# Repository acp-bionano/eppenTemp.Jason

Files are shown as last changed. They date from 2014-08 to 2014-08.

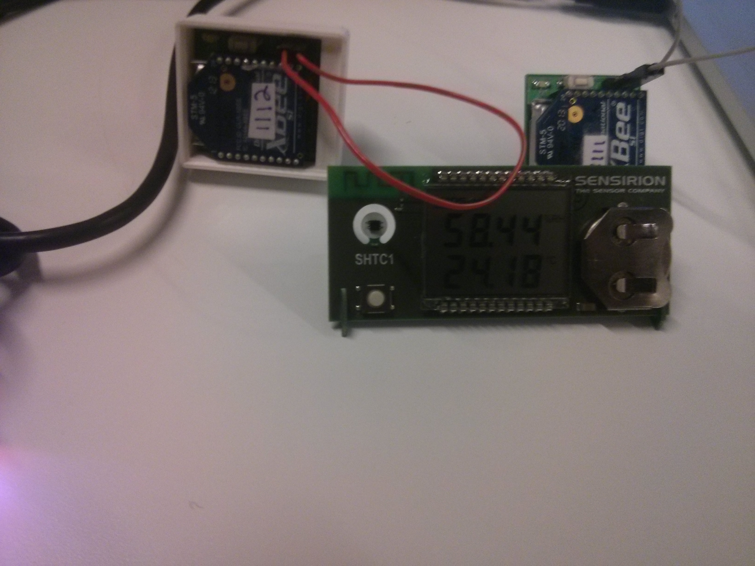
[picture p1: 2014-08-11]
test/tests 08:02/room temp without sleep/ID reference.jpg

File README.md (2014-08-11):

Eppendorf-sized Temperature Sensor
=========
by Andrew Payne and Charles Fracchia

We created a networked temperature sensor that is designed to have the same lower footprint as an eppendorf tube. These sensors are designed to allow the continuous collection of sample temperature in molecular biology experiments.
It is designed to interface with the [Protocol Descriptor Language]() web-system and provide quantifiable information about temperature variability in your protocols.

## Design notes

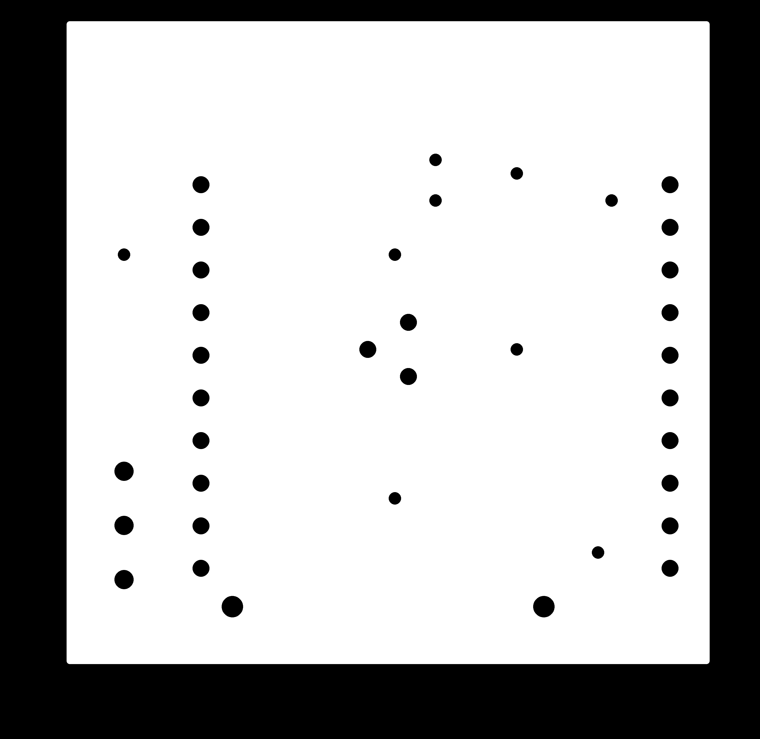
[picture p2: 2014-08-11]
network/draft/outline.png

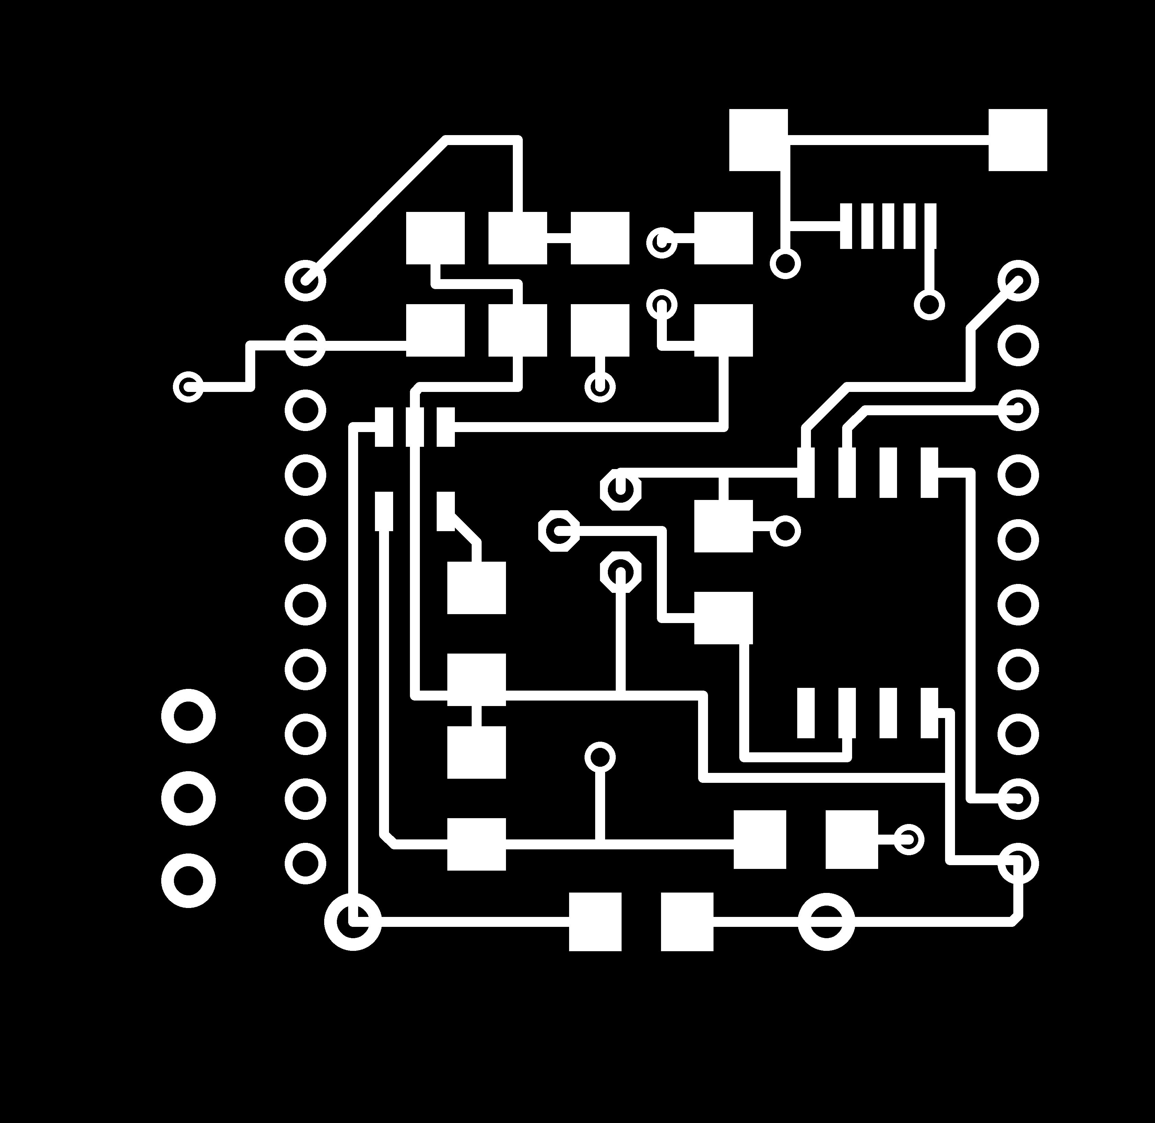
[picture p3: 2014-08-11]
network/draft/traces.png

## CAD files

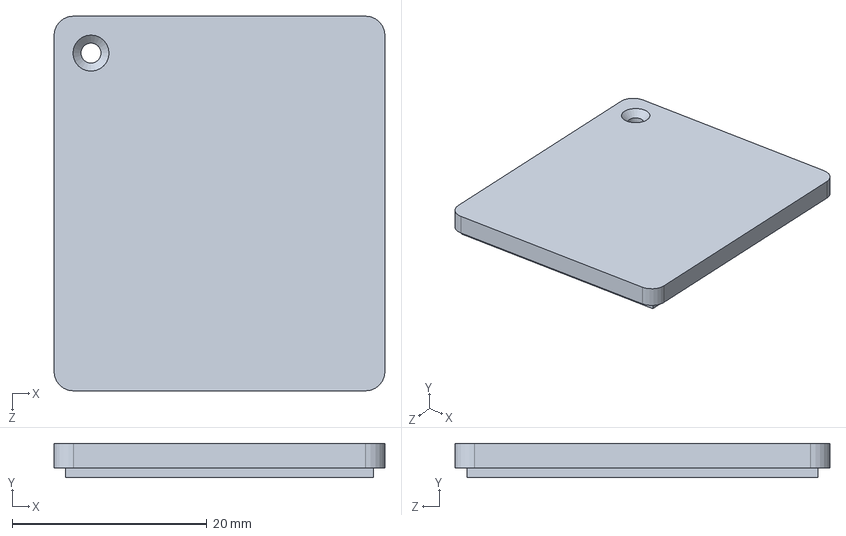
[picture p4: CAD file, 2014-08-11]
case/top casing.SLDPRT
34.0 x 3.50 x 38.5 mm

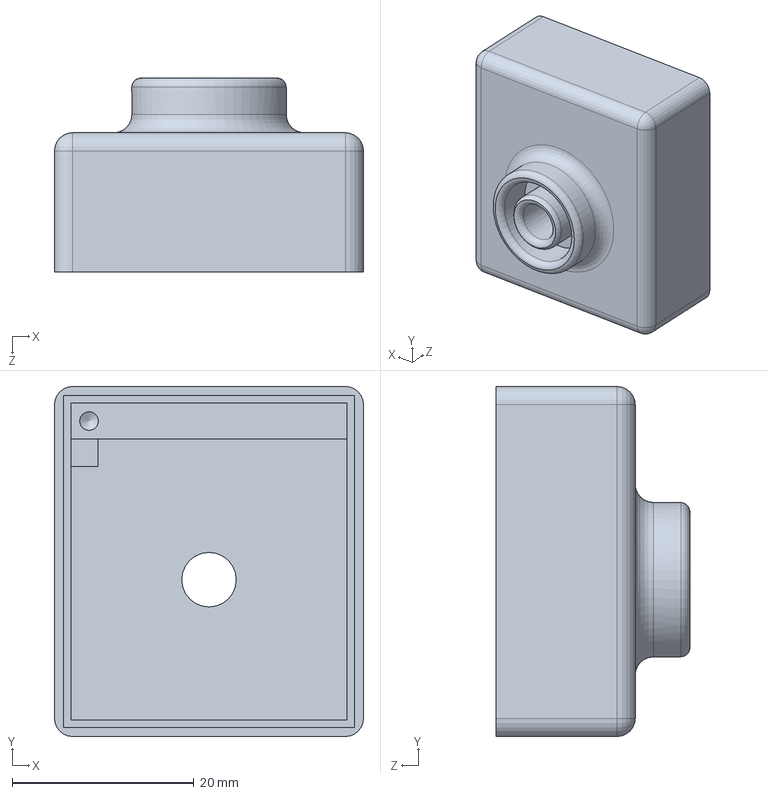
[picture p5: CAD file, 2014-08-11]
case/bottom casing.SLDPRT
34.0 x 38.5 x 21.3 mm

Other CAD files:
case/bottom casing.STL
case/top casing.STL

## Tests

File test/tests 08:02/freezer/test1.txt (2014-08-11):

 1112 25.19 1407113210969
 1112 25.19 1407113212007
 1112 25.19 1407113213047
 1112 25.25 1407113214087
 1112 25.37 1407113215127
 1112 25.37 1407113216166
 1112 25.44 1407113217206
 1112 25.50 1407113218246
 1112 25.62 1407113219285
 1112 25.69 1407113220325
 1112 25.69 1407113221365
 1112 25.62 1407113222404
 1112 25.56 1407113223444
 1112 25.56 1407113224499
 1112 25.50 1407113225539
 1112 25.44 1407113226579
 1112 25.31 1407113227618
 1112 25.25 1407113228658
 1112 25.19 1407113230737
 1112 25.06 1407113231777
 1112 25.44 1407113233856
 1112 25.50 1407113234896
 1112 25.50 1407113235935
 1112 25.50 1407113236975
 1112 25.50 1407113238014
 1112 25.37 1407113239054
 1112 25.00 1407113241149
 1112 24.62 1407113242189
 1112 23.87 1407113243229
 1112 23.19 1407113244252
 1112 22.62 1407113245308
 1112 22.12 1407113246348
 1112 21.56 1407113247387
 1112 21.12 1407113248427
 1112 20.87 1407113249466
 1112 20.62 1407113250506
 1112 20.50 1407113251546
 1112 20.19 1407113252586
 1112 19.87 1407113253625
 1112 19.56 1407113254665
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

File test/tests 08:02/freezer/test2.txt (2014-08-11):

 1112 25.06 1407121928122
 1112 25.44 1407121957791
 1112 25.50 1407121987460
 1112 21.56 1407122017130
 1112 13.19 1407122046816
 1112 10.75 1407122076518
 1112 8.75 1407122106219
 1112 6.81 1407122135921
 1112 5.44 1407122165623
 1112 4.13 1407122195341
 1112 2.75 1407122225058
 1112 1.69 1407122254776
 1112 0.63 1407122284509
 1112 -0.19 1407122314227
 1112 -1.00 1407122343897
 1112 -1.56 1407122373614
 1112 -2.31 1407122403333
 1112 -2.81 1407122433050
 1112 -3.38 1407122462784
 1112 -3.81 1407122492517
 1112 -4.31 1407122522235
 1112 -5.31 1407122551969
 1112 -6.50 1407122581702
 1112 -7.31 1407122611436
 1112 -8.06 1407122641170
 1112 -8.88 1407122670904
 1112 -9.56 1407122700638
 1112 -10.13 1407122730387
 1112 -10.56 1407122760137
 1112 -10.94 1407122789895
 1112 -11.25 1407122819623
 1112 -11.56 1407122849356
 1112 -11.81 1407122879090
 1112 -12.06 1407122908824
 1112 -12.31 1407122938557
 1112 -12.56 1407122968291
 1112 -12.69 1407122998041
 1112 -12.94 1407123027775
 1112 -13.13 1407123057524
 1112 -13.31 1407123087274
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

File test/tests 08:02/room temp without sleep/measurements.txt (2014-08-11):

ID=1112 R=26ID=1112 R=26.87 t= 1407040778535
ID=1112 R=26.87 t= 1407040779590
ID=1112 R=26.94 t= 1407040780630
ID=1112 R=26.94 t= 1407040781669
ID=1111 R=25.19 t= 1407040782405
ID=1112 R=26.94 t= 1407040782709
ID=1111 R=25.25 t= 1407040783445
ID=1112 R=26.94 t= 1407040783749
ID=1111 R=25.25 t= 1407040784484
ID=1112 R=27.00 t= 1407040784804
ID=1111 R=25.25 t= 1407040785540
ID=1112 R=26.94 t= 1407040785844
ID=1111 R=25.25 t= 1407040786580
ID=1112 R=27.00 t= 1407040786884
ID=1111 R=25.31 t= 1407040787620
ID=1112 R=27.00 t= 1407040787923
ID=1111 R=25.31 t= 1407040788659
ID=1112 R=27.00 t= 1407040788963
ID=1111 R=25.31 t= 1407040789699
ID=1112 R=27.00 t= 1407040790018
ID=1111 R=25.31 t= 1407040790738
ID=1112 R=27.00 t= 1407040791058
ID=1111 R=25.31 t= 1407040791778
ID=1112 R=27.00 t= 1407040792098
ID=1111 R=25.31 t= 1407040792817
ID=1112 R=27.00 t= 1407040793137
ID=1111 R=25.31 t= 1407040793857
ID=1112 R=27.06 t= 1407040794177
ID=1111 R=25.37 t= 1407040794897
ID=1112 R=27.06 t= 1407040795233
ID=1111 R=25.37 t= 1407040795937
ID=1112 R=27.06 t= 1407040796272
ID=1111 R=25.37 t= 1407040796976
ID=1112 R=27.06 t= 1407040797312
ID=1111 R=25.37 t= 1407040798015
ID=1112 R=27.06 t= 1407040798351
ID=1111 R=25.44 t= 1407040799055
ID=1112 R=27.06 t= 1407040799391
ID=1111 R=25.44 t= 1407040800095
ID=1112 R=27.06 t= 1407040800431
ID=1111 R=25.50 t= 1407040801134
ID=1112 R=27.12 t= 1407040801486
ID=1111 R=25.50 t= 1407040802174
ID=1112 R=27.12 t= 1407040802526
ID=1111 R=25.50 t= 1407040803214
ID=1112 R=27.12 t= 1407040803566
ID=1111 R=25.56 t= 1407040804254
ID=1112 R=27.12 t= 1407040804605
ID=1111 R=25.56 t= 1407040805293
ID=1112 R=27.12 t= 1407040805645
ID=1111 R=25.56 t= 1407040806333
ID=1112 R=27.12 t= 1407040806701
ID=1111 R=25.56 t= 1407040807372
ID=1112 R=27.12 t= 1407040807740
ID=1111 R=25.56 t= 1407040808412
ID=1112 R=27.12 t= 1407040808780
ID=1111 R=25.56 t= 1407040809468
ID=1112 R=27.19 t= 1407040809819
ID=1111 R=25.56 t= 1407040810507
ID=1112 R=27.12 t= 1407040810859
ID=1111 R=25.56 t= 1407040811547
ID=1112 R=27.12 t= 1407040811915
ID=1111 R=25.56 t= 1407040812586
ID=1112 R=27.19 t= 1407040812954
ID=1111 R=25.56 t= 1407040813626
ID=1112 R=27.19 t= 1407040813995
ID=1111 R=25.56 t= 1407040814666
ID=1112 R=27.19 t= 1407040815033
ID=1111 R=25.62 t= 1407040815705
ID=1112 R=27.19 t= 1407040816073
ID=1111 R=25.62 t= 1407040816745
ID=1112 R=27.19 t= 1407040817129
ID=1111 R=25.62 t= 1407040817784
ID=1112 R=27.19 t= 1407040818168
ID=1111 R=25.62 t= 1407040818824
ID=1112 R=27.19 t= 1407040819208
ID=1111 R=25.62 t= 1407040819864
ID=1112 R=27.19 t= 1407040820248
ID=1111 R=25.62 t= 1407040820904
ID=1112 R=27.19 t= 1407040821287
ID=1111 R=25.62 t= 1407040821943
ID=1112 R=27.25 t= 1407040822327
ID=1111 R=25.62 t= 1407040822983
ID=1112 R=27.19 t= 1407040823383
ID=1111 R=25.62 t= 1407040824022
ID=1112 R=27.25 t= 1407040824422
ID=1111 R=25.69 t= 1407040825062
ID=1112 R=27.25 t= 1407040825462
ID=1111 R=25.69 t= 1407040826101
ID=1112 R=27.25 t= 1407040826501
ID=1111 R=25.69 t= 1407040827157
ID=1112 R=27.25 t= 1407040827557
ID=1111 R=25.75 t= 1407040828197
ID=1112 R=27.25 t= 1407040828597
ID=1111 R=25.69 t= 1407040829236
ID=1112 R=27.25 t= 1407040829636
ID=1111 R=25.75 t= 1407040830276
ID=1112 R=27.25 t= 1407040830676
ID=1111 R=25.75 t= 1407040831316
ID=1112 R=27.25 t= 1407040831715
ID=1111 R=25.75 t= 1407040832355
ID=1112 R=27.31 t= 1407040832755
ID=1111 R=25.75 t= 1407040833395
ID=1112 R=27.25 t= 1407040833811
ID=1111 R=25.75 t= 1407040834435
ID=1112 R=27.31 t= 1407040834851
ID=1111 R=25.81 t= 1407040835474
ID=1112 R=27.31 t= 1407040835890
ID=1111 R=25.81 t= 1407040836514
ID=1112 R=27.31 t= 1407040836930
ID=1111 R=25.81 t= 1407040837553
ID=1112 R=27.31 t= 1407040837969
ID=1111 R=25.87 t= 1407040838593
ID=1112 R=27.31 t= 1407040839025
ID=1111 R=25.81 t= 1407040839633
ID=1112 R=27.31 t= 1407040840065
ID=1111 R=25.87 t= 1407040840672
ID=1112 R=27.31 t= 1407040841104
ID=1111 R=25.87 t= 1407040841712
ID=1112 R=27.37 t= 1407040842144
ID=1111 R=25.87 t= 1407040842751
ID=1112 R=27.31 t= 1407040843183
ID=1111 R=25.94 t= 1407040843791
ID=1112 R=27.37 t= 1407040844225
ID=1111 R=25.87 t= 1407040844847
ID=1112 R=27.37 t= 1407040845279
ID=1111 R=25.94 t= 1407040845886
ID=1112 R=27.37 t= 1407040846318
ID=1111 R=25.94 t= 1407040846926
ID=1112 R=27.37 t= 1407040847358
ID=1111 R=25.94 t= 1407040847966
ID=1112 R=27.37 t= 1407040848398
ID=1111 R=26.00 t= 1407040849005
ID=1112 R=27.37 t= 1407040849437
ID=1111 R=25.94 t= 1407040850045
ID=1112 R=27.44 t= 1407040850477
ID=1111 R=25.94 t= 1407040851085
ID=1112 R=27.44 t= 1407040851517
ID=1111 R=26.00 t= 1407040852125
ID=1112 R=27.37 t= 1407040852572
ID=1111 R=26.00 t= 1407040853164
ID=1112 R=27.37 t= 1407040853612
ID=1111 R=26.00 t= 1407040854204
ID=1112 R=27.44 t= 1407040854652
ID=1111 R=26.06 t= 1407040855243
ID=1112 R=27.37 t= 1407040855691
ID=1111 R=26.06 t= 1407040856283
ID=1112 R=27.44 t= 1407040856731
ID=1111 R=26.00 t= 1407040857322
ID=1112 R=27.44 t= 1407040857786
ID=1111 R=26.00 t= 1407040858362
ID=1112 R=27.44 t= 1407040858826
ID=1111 R=26.00 t= 1407040859402
ID=1112 R=27.44 t= 1407040859865
ID=1111 R=26.00 t= 1407040860441
ID=1112 R=27.44 t= 1407040860905
ID=1111 R=26.00 t= 1407040861497
ID=1112 R=27.50 t= 1407040861945
ID=1111 R=26.00 t= 1407040862537
ID=1112 R=27.44 t= 1407040863000
ID=1111 R=26.00 t= 1407040863576
ID=1112 R=27.50 t= 1407040864040
ID=1111 R=26.00 t= 1407040864616
ID=1112 R=27.50 t= 1407040865080
ID=1111 R=26.00 t= 1407040865656
ID=1112 R=27.50 t= 1407040866119
ID=1111 R=26.00 t= 1407040866695
ID=1112 R=27.50 t= 1407040867159
ID=1111 R=26.00 t= 1407040867734
ID=1112 R=27.50 t= 1407040868214
ID=1111 R=26.00 t= 1407040868774
ID=1112 R=27.50 t= 1407040869254
ID=1111 R=26.06 t= 1407040869814
ID=1112 R=27.50 t= 1407040870294
ID=1111 R=26.06 t= 1407040870854
ID=1112 R=27.50 t= 1407040871333
ID=1111 R=26.06 t= 1407040871893
ID=1112 R=27.56 t= 1407040872373
ID=1111 R=26.06 t= 1407040872933
ID=1112 R=27.50 t= 1407040873429
ID=1111 R=26.06 t= 1407040873972
ID=1112 R=27.50 t= 1407040874468
ID=1111 R=26.12 t= 1407040875012
ID=1112 R=27.56 t= 1407040875508
ID=1111 R=26.12 t= 1407040876052
ID=1112 R=27.50 t= 1407040876548
ID=1111 R=26.12 t= 1407040877092
ID=1112 R=27.56 t= 1407040877587
ID=1111 R=26.12 t= 1407040878131
ID=1112 R=27.56 t= 1407040878643
ID=1111 R=26.19 t= 1407040879170
ID=1112 R=27.56 t= 1407040879682
ID=1111 R=26.19 t= 1407040880210
ID=1112 R=27.56 t= 1407040880722
ID=1111 R=26.19 t= 1407040881266
ID=1112 R=27.56 t= 1407040881762
ID=1111 R=26.19 t= 1407040882305
ID=1112 R=27.56 t= 1407040882801
ID=1111 R=26.19 t= 1407040883345
ID=1112 R=27.56 t= 1407040883857
ID=1111 R=26.25 t= 1407040884385
ID=1112 R=27.56 t= 1407040884897
ID=1111 R=26.19 t= 1407040885425
ID=1112 R=27.62 t= 1407040885936
ID=1111 R=26.25 t= 1407040886464
ID=1112 R=27.62 t= 1407040886976
ID=1111 R=26.25 t= 1407040887504
ID=1112 R=27.56 t= 1407040888015
ID=1111 R=26.19 t= 1407040888543
ID=1112 R=27.62 t= 1407040889071
ID=1111 R=26.25 t= 1407040889583
ID=1112 R=27.62 t= 1407040890111
ID=1111 R=26.31 t= 1407040890623
ID=1112 R=27.62 t= 1407040891150
ID=1111 R=26.25 t= 1407040891662
ID=1112 R=27.62 t= 1407040892190
ID=1111 R=26.31 t= 1407040892702
ID=1112 R=27.62 t= 1407040893229
ID=1111 R=26.31 t= 1407040893741
ID=1112 R=27.62 t= 1407040894285
ID=1111 R=26.31 t= 1407040894781
ID=1112 R=27.69 t= 1407040895325
ID=1111 R=26.31 t= 1407040895821
ID=1112 R=27.69 t= 1407040896364
ID=1111 R=26.31 t= 1407040896860
ID=1112 R=27.69 t= 1407040897404
ID=1111 R=26.31 t= 1407040897900
ID=1112 R=27.69 t= 1407040898444
ID=1111 R=26.25 t= 1407040898939
ID=1112 R=27.69 t= 1407040899483
ID=1111 R=26.31 t= 1407040899979
ID=1112 R=27.69 t= 1407040900539
ID=1111 R=26.25 t= 1407040901019
ID=1112 R=27.69 t= 1407040901578
ID=1111 R=26.31 t= 1407040902058
ID=1112 R=27.69 t= 1407040902618
ID=1111 R=26.31 t= 1407040903114
ID=1112 R=27.69 t= 1407040903658
ID=1111 R=26.31 t= 1407040904153
ID=1112 R=27.69 t= 1407040904697
ID=1111 R=26.31 t= 1407040905193
ID=1112 R=27.69 t= 1407040905737
ID=1111 R=26.31 t= 1407040906233
ID=1112 R=27.69 t= 1407040906793
ID=1111 R=26.31 t= 1407040907272
ID=1112 R=27.69 t= 1407040907832
ID=1111 R=26.31 t= 1407040908312
ID=1112 R=27.69 t= 1407040908872
ID=1111 R=26.31 t= 1407040909352
ID=1112 R=27.75 t= 1407040909911
ID=1111 R=26.37 t= 1407040910391
ID=1112 R=27.75 t= 1407040910951
ID=1111 R=26.31 t= 1407040911431
ID=1112 R=27.75 t= 1407040911991
ID=1111 R=26.31 t= 1407040912470
ID=1112 R=27.75 t= 1407040913046
ID=1111 R=26.37 t= 1407040913510
ID=1112 R=27.75 t= 1407040914086
ID=1111 R=26.37 t= 1407040914550
ID=1112 R=27.75 t= 1407040915126
ID=1111 R=26.37 t= 1407040915589
ID=1112 R=27.75 t= 1407040916165
ID=1111 R=26.37 t= 1407040916629
ID=1112 R=27.75 t= 1407040917205
ID=1111 R=26.37 t= 1407040917669
ID=1112 R=27.75 t= 1407040918260
ID=1111 R=26.37 t= 1407040918708
ID=1112 R=27.75 t= 1407040919300
ID=1111 R=26.37 t= 1407040919764
ID=1112 R=27.81 t= 1407040920340
ID=1111 R=26.37 t= 1407040920803
ID=1112 R=27.75 t= 1407040921379
ID=1111 R=26.37 t= 1407040921843
ID=1112 R=27.81 t= 1407040922435
ID=1111 R=26.44 t= 1407040922883
ID=1112 R=27.81 t= 1407040923475
ID=1111 R=26.44 t= 1407040923922
ID=1112 R=27.81 t= 1407040924514
ID=1111 R=26.44 t= 1407040924962
ID=1112 R=27.81 t= 1407040925554
ID=1111 R=26.44 t= 1407040926001
ID=1112 R=27.81 t= 1407040926593
ID=1111 R=26.50 t= 1407040927041
ID=1112 R=27.81 t= 1407040927649
ID=1111 R=26.50 t= 1407040928081
ID=1112 R=27.81 t= 1407040928688
ID=1111 R=26.50 t= 1407040929120
ID=1112 R=27.81 t= 1407040929728
ID=1111 R=26.50 t= 1407040930160
ID=1112 R=27.81 t= 1407040930768
ID=1111 R=26.56 t= 1407040931200
ID=1112 R=27.81 t= 1407040931807
ID=1111 R=26.56 t= 1407040932239
ID=1112 R=27.81 t= 1407040932847
ID=1111 R=26.56 t= 1407040933279
ID=1112 R=27.81 t= 1407040933902
ID=1111 R=26.56 t= 1407040934318
ID=1112 R=27.87 t= 1407040934942
ID=1111 R=26.56 t= 1407040935374
ID=1112 R=27.87 t= 1407040935982
ID=1111 R=26.56 t= 1407040936414
ID=1112 R=27.87 t= 1407040937022
ID=1111 R=26.56 t= 1407040937454
ID=1112 R=27.87 t= 1407040938061
ID=1111 R=26.56 t= 1407040938493
ID=1112 R=27.87 t= 1407040939117
ID=1111 R=26.56 t= 1407040939533
ID=1112 R=27.87 t= 1407040940156
ID=1111 R=26.56 t= 1407040940572
ID=1112 R=27.87 t= 1407040941196
ID=1111 R=26.56 t= 1407040941612
ID=1112 R=27.87 t= 1407040942236
ID=1111 R=26.56 t= 1407040942651
ID=1112 R=27.87 t= 1407040943275
ID=1111 R=26.56 t= 1407040943691
ID=1112 R=27.87 t= 1407040944331
ID=1111 R=26.56 t= 1407040944731
ID=1112 R=27.87 t= 1407040945371
ID=1111 R=26.56 t= 1407040945771
ID=1112 R=27.94 t= 1407040946410
ID=1111 R=26.56 t= 1407040946810
ID=1112 R=27.94 t= 1407040947450
ID=1111 R=26.62 t= 1407040947850
ID=1112 R=27.94 t= 1407040948489
ID=1111 R=26.62 t= 1407040948889
ID=1112 R=27.94 t= 1407040949529
ID=1111 R=26.62 t= 1407040949929
ID=1112 R=27.94 t= 1407040950585
ID=1111 R=26.62 t= 1407040950984
ID=1112 R=27.94 t= 1407040951624
ID=1111 R=26.62 t= 1407040952024
ID=1112 R=27.94 t= 1407040952664
ID=1111 R=26.62 t= 1407040953064
ID=1112 R=27.94 t= 1407040953704
ID=1111 R=26.62 t= 1407040954103
ID=1112 R=27.94 t= 1407040954743
ID=1111 R=26.62 t= 1407040955143
ID=1112 R=27.94 t= 1407040955799
ID=1111 R=26.62 t= 1407040956182
ID=1112 R=27.94 t= 1407040956838
ID=1111 R=26.62 t= 1407040957222
ID=1112 R=27.94 t= 1407040957878
ID=1111 R=26.69 t= 1407040958262
ID=1112 R=27.94 t= 1407040958918
ID=1111 R=26.69 t= 1407040959301
ID=1112 R=27.94 t= 1407040959957
ID=1111 R=26.69 t= 1407040960341
ID=1112 R=27.94 t= 1407040960997
ID=1111 R=26.69 t= 1407040961381
ID=1112 R=27.94 t= 1407040962036
ID=1111 R=26.75 t= 1407040962420
ID=1112 R=28.00 t= 1407040963092
ID=1111 R=26.75 t= 1407040963460
ID=1112 R=27.94 t= 1407040964131
ID=1111 R=26.69 t= 1407040964499
ID=1112 R=28.00 t= 1407040965171
ID=1111 R=26.75 t= 1407040965539
ID=1112 R=28.00 t= 1407040966211
ID=1111 R=26.75 t= 1407040966579
ID=1112 R=28.00 t= 1407040967251
ID=1111 R=26.75 t= 1407040967618
ID=1112 R=28.00 t= 1407040968290
ID=1111 R=26.75 t= 1407040968658
ID=1112 R=28.00 t= 1407040969346
ID=1111 R=26.75 t= 1407040969698
ID=1112 R=28.00 t= 1407040970386
ID=1111 R=26.75 t= 1407040970738
ID=1112 R=28.00 t= 1407040971425
ID=1111 R=26.69 t= 1407040971777
ID=1112 R=28.06 t= 1407040972465
ID=1111 R=26.75 t= 1407040972833
ID=1112 R=28.00 t= 1407040973505
ID=1111 R=26.75 t= 1407040973873
ID=1112 R=28.00 t= 1407040974544
ID=1111 R=26.75 t= 1407040974912
ID=1112 R=28.06 t= 1407040975584
ID=1111 R=26.75 t= 1407040975952
ID=1112 R=28.06 t= 1407040976639
ID=1111 R=26.75 t= 1407040976991
ID=1112 R=28.06 t= 1407040977679
ID=1111 R=26.75 t= 1407040978031
ID=1112 R=28.06 t= 1407040978719
ID=1111 R=26.75 t= 1407040979070
ID=1112 R=28.06 t= 1407040979758
ID=1111 R=26.75 t= 1407040980110
ID=1112 R=28.06 t= 1407040980798
ID=1111 R=26.69 t= 1407040981150
ID=1112 R=28.06 t= 1407040981838
ID=1111 R=26.75 t= 1407040982189
ID=1112 R=28.06 t= 1407040982893
ID=1111 R=26.75 t= 1407040983229
ID=1112 R=28.06 t= 1407040983933
ID=1111 R=26.81 t= 1407040984269
ID=1112 R=28.06 t= 1407040984972
ID=1111 R=26.81 t= 1407040985308
ID=1112 R=28.06 t= 1407040986012
ID=1111 R=26.81 t= 1407040986348
ID=1112 R=28.06 t= 1407040987051
ID=1111 R=26.81 t= 1407040987388
ID=1112 R=28.06 t= 1407040988091
ID=1111 R=26.81 t= 1407040988427
ID=1112 R=28.06 t= 1407040989131
ID=1111 R=26.87 t= 1407040989467
ID=1112 R=28.06 t= 1407040990187
ID=1111 R=26.87 t= 1407040990506
ID=1112 R=28.12 t= 1407040991226
ID=1111 R=26.87 t= 1407040991546
ID=1112 R=28.12 t= 1407040992266
ID=1111 R=26.87 t= 1407040992586
ID=1112 R=28.06 t= 1407040993306
ID=1111 R=26.87 t= 1407040993625
ID=1112 R=28.12 t= 1407040994345
ID=1111 R=26.94 t= 1407040994665
ID=1112 R=28.12 t= 1407040995401
ID=1111 R=26.94 t= 1407040995704
ID=1112 R=28.06 t= 1407040996440
ID=1111 R=26.94 t= 1407040996760
ID=1112 R=28.12 t= 1407040997480
ID=1111 R=27.00 t= 1407040997800
ID=1112 R=28.12 t= 1407040998520
ID=1111 R=26.94 t= 1407040998839
ID=1112 R=28.12 t= 1407040999559
ID=1111 R=26.94 t= 1407040999879
ID=1112 R=28.12 t= 1407041000615
ID=1111 R=26.94 t= 1407041000919
ID=1112 R=28.12 t= 1407041001655
ID=1111 R=26.94 t= 1407041001958
ID=1112 R=28.12 t= 1407041002694
ID=1111 R=26.94 t= 1407041002998
ID=1112 R=28.12 t= 1407041003734
ID=1111 R=26.94 t= 1407041004038
ID=1112 R=28.19 t= 1407041004773
ID=1111 R=26.94 t= 1407041005077
ID=1112 R=28.12 t= 1407041005813
ID=1111 R=26.87 t= 1407041006117
ID=1112 R=28.12 t= 1407041006853
ID=1111 R=26.94 t= 1407041007157
ID=1112 R=28.12 t= 1407041007908
ID=1111 R=26.94 t= 1407041008196
ID=1112 R=28.12 t= 1407041008948
ID=1111 R=26.94 t= 1407041009236
ID=1112 R=28.12 t= 1407041009987
ID=1111 R=26.94 t= 1407041010276
ID=1112 R=28.19 t= 1407041011027
ID=1111 R=26.94 t= 1407041011315
ID=1112 R=28.19 t= 1407041012067
ID=1111 R=26.94 t= 1407041012355
ID=1112 R=28.19 t= 1407041013106
ID=1111 R=26.94 t= 1407041013394
ID=1112 R=28.19 t= 1407041014162
ID=1111 R=26.94 t= 1407041014434
ID=1112 R=28.19 t= 1407041015202
ID=1111 R=26.94 t= 1407041015474
ID=1112 R=28.19 t= 1407041016241
ID=1111 R=26.94 t= 1407041016513
ID=1112 R=28.19 t= 1407041017281
ID=1111 R=26.94 t= 1407041017553
ID=1112 R=28.19 t= 1407041018321
ID=1111 R=26.94 t= 1407041018609
ID=1112 R=28.19 t= 1407041019360
ID=1111 R=26.94 t= 1407041019648
ID=1112 R=28.19 t= 1407041020400
ID=1111 R=27.00 t= 1407041020688
ID=1112 R=28.19 t= 1407041021455
ID=1111 R=27.00 t= 1407041021727
ID=1112 R=28.19 t= 1407041022495
ID=1111 R=27.00 t= 1407041022767
ID=1112 R=28.19 t= 1407041023534
ID=1111 R=27.06 t= 1407041023807
ID=1112 R=28.19 t= 1407041024574
ID=1111 R=27.06 t= 1407041024846
ID=1112 R=28.25 t= 1407041025614
ID=1111 R=27.06 t= 1407041025886
ID=1112 R=28.19 t= 1407041026670
ID=1111 R=27.06 t= 1407041026925
ID=1112 R=28.25 t= 1407041027709
ID=1111 R=27.06 t= 1407041027965
ID=1112 R=28.25 t= 1407041028749
ID=1111 R=27.06 t= 1407041029005
ID=1112 R=28.25 t= 1407041029788
ID=1111 R=27.12 t= 1407041030044
ID=1112 R=28.25 t= 1407041030828
ID=1111 R=27.12 t= 1407041031084
ID=1112 R=28.25 t= 1407041031867
ID=1111 R=27.12 t= 1407041032123
ID=1112 R=28.25 t= 1407041032923
ID=1111 R=27.12 t= 1407041033163
ID=1112 R=28.25 t= 1407041033963
ID=1111 R=27.12 t= 1407041034203
ID=1112 R=28.25 t= 1407041035002
ID=1111 R=27.19 t= 1407041035242
ID=1112 R=28.25 t= 1407041036042
ID=1111 R=27.19 t= 1407041036282
ID=1112 R=28.25 t= 1407041037082
ID=1111 R=27.19 t= 1407041037338
ID=1112 R=28.25 t= 1407041038121
ID=1111 R=27.19 t= 1407041038377
ID=1112 R=28.25 t= 1407041039161
ID=1111 R=27.19 t= 1407041039417
ID=1112 R=28.25 t= 1407041040217
ID=1111 R=27.19 t= 1407041040456
ID=1112 R=28.25 t= 1407041041256
ID=1111 R=27.25 t= 1407041041496
ID=1112 R=28.25 t= 1407041042296
ID=1111 R=27.19 t= 1407041042536
ID=1112 R=28.31 t= 1407041043335
ID=1111 R=27.19 t= 1407041043575
ID=1112 R=28.31 t= 1407041044375
ID=1111 R=27.25 t= 1407041044615
ID=1112 R=28.31 t= 1407041045431
ID=1111 R=27.25 t= 1407041045655
ID=1112 R=28.31 t= 1407041046470
ID=1111 R=27.25 t= 1407041046694
ID=1112 R=28.25 t= 1407041047510
ID=1111 R=27.25 t= 1407041047734
ID=1112 R=28.25 t= 1407041048549
ID=1111 R=27.25 t= 1407041048773
ID=1112 R=28.25 t= 1407041049589
ID=1111 R=27.25 t= 1407041049813
ID=1112 R=28.31 t= 1407041050645
ID=1111 R=27.25 t= 1407041050853
ID=1112 R=28.31 t= 1407041051684
ID=1111 R=27.25 t= 1407041051892
ID=1112 R=28.31 t= 1407041052724
ID=1111 R=27.25 t= 1407041052932
ID=1112 R=28.31 t= 1407041053764
ID=1111 R=27.25 t= 1407041053971
ID=1112 R=28.31 t= 1407041054803
ID=1111 R=27.25 t= 1407041055011
ID=1112 R=28.31 t= 1407041055859
ID=1111 R=27.25 t= 1407041056051
ID=1112 R=28.31 t= 1407041056898
ID=1111 R=27.31 t= 1407041057090
ID=1112 R=28.31 t= 1407041057938
ID=1111 R=27.25 t= 1407041058130
ID=1112 R=28.31 t= 1407041058978
ID=1111 R=27.31 t= 1407041059170
ID=1112 R=28.31 t= 1407041060017
ID=1111 R=27.31 t= 1407041060209
ID=1112 R=28.31 t= 1407041061057
ID=1111 R=27.31 t= 1407041061249
ID=1112 R=28.31 t= 1407041062097
ID=1111 R=27.31 t= 1407041062288
ID=1112 R=28.31 t= 1407041063152
ID=1111 R=27.31 t= 1407041063344
ID=1112 R=28.31 t= 1407041064192
ID=1111 R=27.37 t= 1407041064384
ID=1112 R=28.31 t= 1407041065232
ID=1111 R=27.37 t= 1407041065423
ID=1112 R=28.31 t= 1407041066271
ID=1111 R=27.37 t= 1407041066463
ID=1112 R=28.31 t= 1407041067310
ID=1111 R=27.31 t= 1407041067502
ID=1112 R=28.31 t= 1407041068350
ID=1111 R=27.31 t= 1407041068542
ID=1112 R=28.37 t= 1407041069406
ID=1111 R=27.31 t= 1407041069582
ID=1112 R=28.37 t= 1407041070445
ID=1111 R=27.31 t= 1407041070622
ID=1112 R=28.37 t= 1407041071485
ID=1111 R=27.31 t= 1407041071661
ID=1112 R=28.37 t= 1407041072525
ID=1111 R=27.37 t= 1407041072701
ID=1112 R=28.37 t= 1407041073564
ID=1111 R=27.31 t= 1407041073741
ID=1112 R=28.37 t= 1407041074604
ID=1111 R=27.31 t= 1407041074780
ID=1112 R=28.37 t= 1407041075660
ID=1111 R=27.31 t= 1407041075820
ID=1112 R=28.37 t= 1407041076699
ID=1111 R=27.31 t= 1407041076859
ID=1112 R=28.37 t= 1407041077739
ID=1111 R=27.31 t= 1407041077899
ID=1112 R=28.37 t= 1407041078779
ID=1111 R=27.31 t= 1407041078939
ID=1112 R=28.37 t= 1407041079818
ID=1111 R=27.31 t= 1407041079978
ID=1112 R=28.37 t= 1407041080874
ID=1111 R=27.25 t= 1407041081018
ID=1112 R=28.37 t= 1407041081913
ID=1111 R=27.25 t= 1407041082057
ID=1112 R=28.44 t= 1407041082953
ID=1111 R=27.25 t= 1407041083097
ID=1112 R=28.37 t= 1407041083993
ID=1111 R=27.25 t= 1407041084137
ID=1112 R=28.37 t= 1407041085033
ID=1111 R=27.31 t= 1407041085176
ID=1112 R=28.44 t= 1407041086088
ID=1111 R=27.31 t= 1407041086216
ID=1112 R=28.44 t= 1407041087127
ID=1111 R=27.31 t= 1407041087256
ID=1112 R=28.44 t= 1407041088167
ID=1111 R=27.31 t= 1407041088295
ID=1112 R=28.44 t= 1407041089207
ID=1111 R=27.31 t= 1407041089335
ID=1112 R=28.44 t= 1407041090247
ID=1111 R=27.31 t= 1407041090374
ID=1112 R=28.44 t= 1407041091286
ID=1111 R=27.31 t= 1407041091414
ID=1112 R=28.44 t= 1407041092342
ID=1111 R=27.31 t= 1407041092454
ID=1112 R=28.44 t= 1407041093382
ID=1111 R=27.31 t= 1407041093509
ID=1112 R=28.44 t= 1407041094421
ID=1111 R=27.31 t= 1407041094549
ID=1112 R=28.44 t= 1407041095461
ID=1111 R=27.37 t= 1407041095588
ID=1112 R=28.44 t= 1407041096500
ID=1111 R=27.31 t= 1407041096628
ID=1112 R=28.44 t= 1407041097540
ID=1111 R=27.31 t= 1407041097668
ID=1112 R=28.44 t= 1407041098596
ID=1111 R=27.37 t= 1407041098708
ID=1112 R=28.44 t= 1407041099635
ID=1111 R=27.31 t= 1407041099747
ID=1112 R=28.44 t= 1407041100675
ID=1111 R=27.31 t= 1407041100787
ID=1112 R=28.44 t= 1407041101715
ID=1111 R=27.31 t= 1407041101827
ID=1112 R=28.44 t= 1407041102754
ID=1111 R=27.31 t= 1407041102866
ID=1112 R=28.44 t= 1407041103794
ID=1111 R=27.37 t= 1407041103906
ID=1112 R=28.50 t= 1407041104849
ID=1111 R=27.31 t= 1407041104945
ID=1112 R=28.44 t= 1407041105889
ID=1111 R=27.31 t= 1407041105985
ID=1112 R=28.44 t= 1407041106929
ID=1111 R=27.31 t= 1407041107024
ID=1112 R=28.50 t= 1407041107968
ID=1111 R=27.31 t= 1407041108064
ID=1112 R=28.44 t= 1407041109008
ID=1111 R=27.31 t= 1407041109120
ID=1112 R=28.50 t= 1407041110047
ID=1111 R=27.31 t= 1407041110159
ID=1112 R=28.50 t= 1407041111103
ID=1111 R=27.31 t= 1407041111199
ID=1112 R=28.50 t= 1407041112142
ID=1111 R=27.37 t= 1407041112239
ID=1112 R=28.50 t= 1407041113182
ID=1111 R=27.37 t= 1407041113278
ID=1112 R=28.50 t= 1407041114222
ID=1111 R=27.37 t= 1407041114318
ID=1112 R=28.50 t= 1407041115261
ID=1111 R=27.37 t= 1407041115357
ID=1112 R=28.50 t= 1407041116301
ID=1111 R=27.44 t= 1407041116397
ID=1112 R=28.50 t= 1407041117358
ID=1111 R=27.44 t= 1407041117437
ID=1112 R=28.50 t= 1407041118396
ID=1111 R=27.44 t= 1407041118476
ID=1112 R=28.50 t= 1407041119436
ID=1111 R=27.44 t= 1407041119516
ID=1112 R=28.50 t= 1407041120475
ID=1111 R=27.44 t= 1407041120555
ID=1112 R=28.50 t= 1407041121515
ID=1111 R=27.37 t= 1407041121595
ID=1112 R=28.50 t= 1407041122555
ID=1111 R=27.37 t= 1407041122635
ID=1112 R=28.50 t= 1407041123611
ID=1111 R=27.37 t= 1407041123674
ID=1112 R=28.50 t= 1407041124650
ID=1111 R=27.37 t= 1407041124714
ID=1112 R=28.50 t= 1407041125690
ID=1111 R=27.37 t= 1407041125754
ID=1112 R=28.50 t= 1407041126730
ID=1111 R=27.37 t= 1407041126793
ID=1112 R=28.50 t= 1407041127769
ID=1111 R=27.37 t= 1407041127833
ID=1112 R=28.56 t= 1407041128809
ID=1111 R=27.37 t= 1407041128889
ID=1112 R=28.50 t= 1407041129848
ID=1111 R=27.37 t= 1407041129928
ID=1112 R=28.56 t= 1407041130904
ID=1111 R=27.37 t= 1407041130968
ID=1112 R=28.50 t= 1407041131943
ID=1111 R=27.37 t= 1407041132008
ID=1112 R=28.50 t= 1407041132983
ID=1111 R=27.37 t= 1407041133047
ID=1112 R=28.56 t= 1407041134023
ID=1111 R=27.37 t= 1407041134087
ID=1112 R=28.50 t= 1407041135062
ID=1111 R=27.37 t= 1407041135127
ID=1112 R=28.56 t= 1407041136102
ID=1111 R=27.37 t= 1407041136166
ID=1112 R=28.50 t= 1407041137157
ID=1111 R=27.37 t= 1407041137206
ID=1112 R=28.56 t= 1407041138197
ID=1111 R=27.44 t= 1407041138245
ID=1112 R=28.50 t= 1407041139237
ID=1111 R=27.37 t= 1407041139285
ID=1112 R=28.56 t= 1407041140276
ID=1111 R=27.44 t= 1407041140325
ID=1112 R=28.56 t= 1407041141316
ID=1111 R=27.44 t= 1407041141364
ID=1112 R=28.50 t= 1407041142356
ID=1111 R=27.44 t= 1407041142404
ID=1112 R=28.56 t= 1407041143411
ID=1111 R=27.44 t= 1407041143443
ID=1112 R=28.56 t= 1407041144451
ID=1111 R=27.44 t= 1407041144483
ID=1112 R=28.56 t= 1407041145491
ID=1111 R=27.44 t= 1407041145522
ID=1112 R=28.56 t= 1407041146530
ID=1111 R=27.44 t= 1407041146562
ID=1112 R=28.56 t= 1407041147570
ID=1111 R=27.50 t= 1407041147602
ID=1112 R=28.56 t= 1407041148609
ID=1111 R=27.50 t= 1407041148642
ID=1112 R=28.56 t= 1407041149649
ID=1111 R=27.50 t= 1407041149681
ID=1112 R=28.56 t= 1407041150705
ID=1111 R=27.50 t= 1407041150721
ID=1112 R=28.56 t= 1407041151744
ID=1111 R=27.50 t= 1407041151760
ID=1112 R=28.56 t= 1407041152784
ID=1111 R=27.50 t= 1407041152800
ID=1112 R=28.56 t= 1407041153824
ID=1111 R=27.50 t= 1407041153856
ID=1112 R=28.56 t= 1407041154863
ID=1111 R=27.50 t= 1407041154895
ID=1112 R=28.56 t= 1407041155919
ID=1111 R=27.56 t= 1407041155935
ID=1112 R=28.56 t= 1407041156958
ID=1111 R=27.56 t= 1407041156974
ID=1112 R=28.56 t= 1407041157998
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

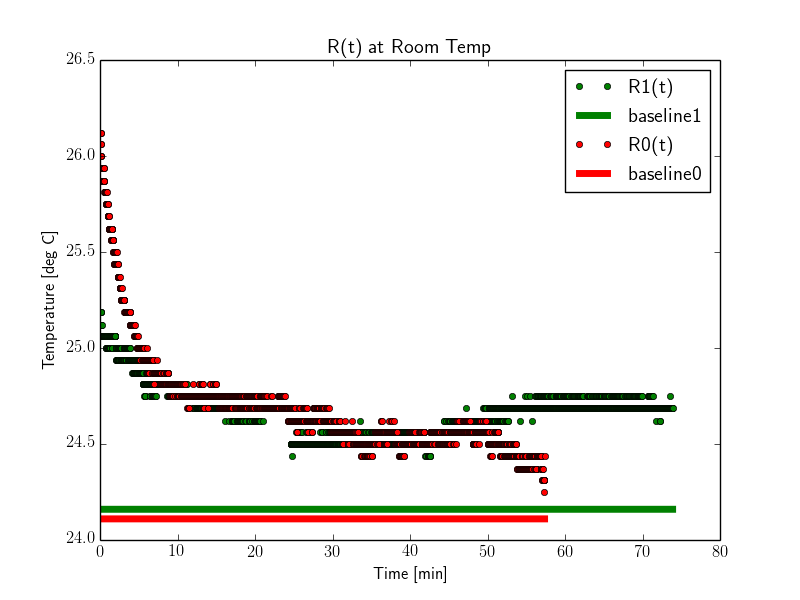
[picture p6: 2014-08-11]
test/tests 08:02/room temp with sleep/combined.png

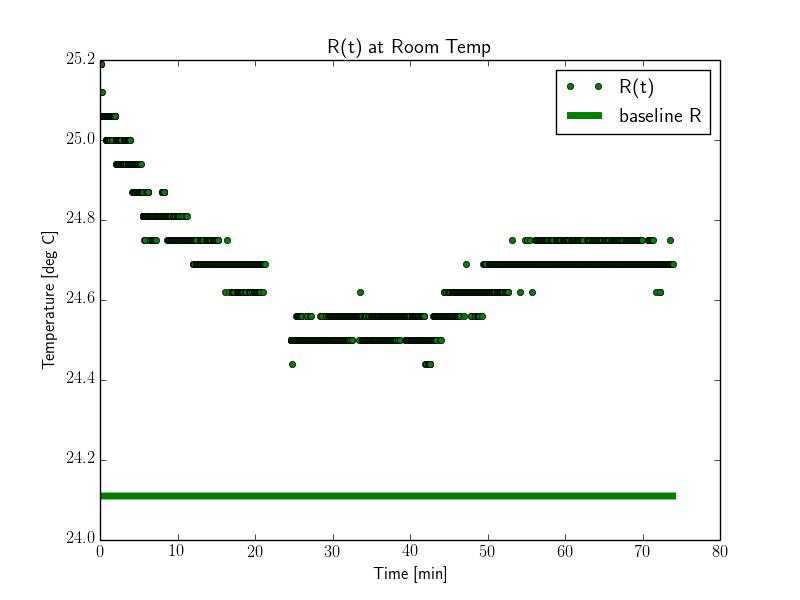
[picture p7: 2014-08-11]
test/tests 08:02/room temp with sleep/rt2.png

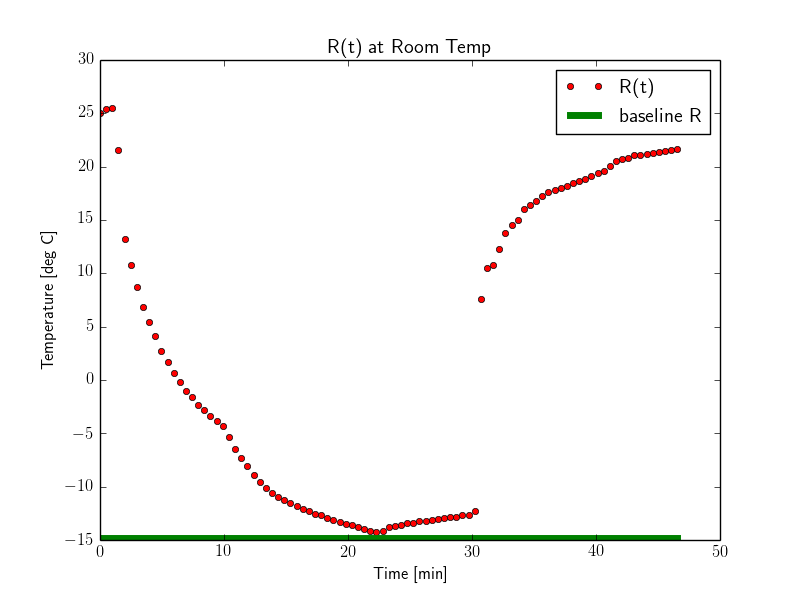
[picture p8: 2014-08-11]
test/tests 08:02/freezer/test2.png

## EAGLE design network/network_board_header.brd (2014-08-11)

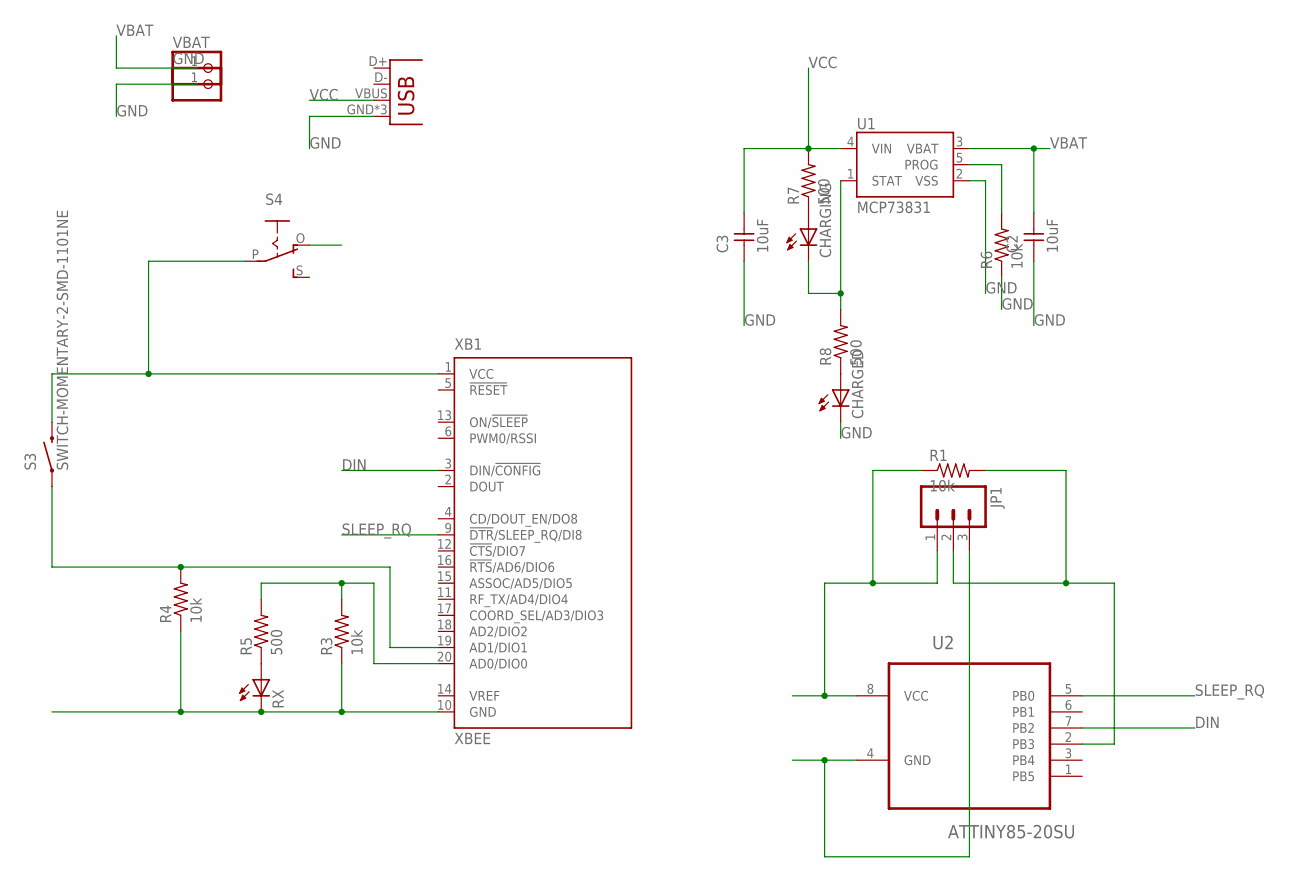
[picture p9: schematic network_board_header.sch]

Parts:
C2, C3: 10uF; 1206
CHARGED: LED1206; 1206
CHARGING: LED1206; 1206
GND: PINHD-1X1CB; 1X01-CLEANBIG
JP1: M03PTH; 1X03
R1: 10k; 1206
R3, R4, R6: 10k; R1206
R5, R7, R8: 500; R1206
RX: LED1206; 1206
S3: SWITCH-MOMENTARY-2-SMD-1101NE; TACTILE-SWITCH-1101NE
S4: EG1218S; EG1218
U1: MCP73831; SOT23-5
U2: ATTINY85-20SU; SOIC127P798X216-8N
VBAT: PINHD-1X1CB; 1X01-CLEANBIG
X1: USB-MICROB
XB1: XBEE

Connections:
DIN: U2.7 (PB2), XB1.3 (DIN/!CONFIG)
GND: C2.1, C3.1, CHARGED.2 (C), GND.1, JP1.3, R3.1, R4.1, R6.1, RX.2 (C), U1.2 (VSS), U2.4 (GND), X1.GND, X1.MT1 (GND), X1.MT2 (GND), XB1.10 (GND)
unnamed: R4.2, S3.P$1 (1), XB1.19 (AD1/DIO1)
unnamed: R5.1, RX.1 (A)
unnamed: R3.2, R5.2, XB1.20 (AD0/DIO0)
unnamed: R6.2, U1.5 (PROG)
unnamed: CHARGING.1 (A), R7.1
unnamed: CHARGED.1 (A), R8.1
unnamed: CHARGING.2 (C), R8.2, U1.1 (STAT)
unnamed: JP1.2, R1.2, U2.2 (PB3)
SLEEP_RQ: U2.5 (PB0), XB1.9 (!DTR!/SLEEP_RQ/DI8)
VBAT: C2.2, S4.O, U1.3 (VBAT), VBAT.1
VCC: C3.2, R7.2, U1.4 (VIN), X1.VBUS
VIN: JP1.1, R1.1, S3.P$2 (2), S4.P, U2.8 (VCC), XB1.1 (VCC)

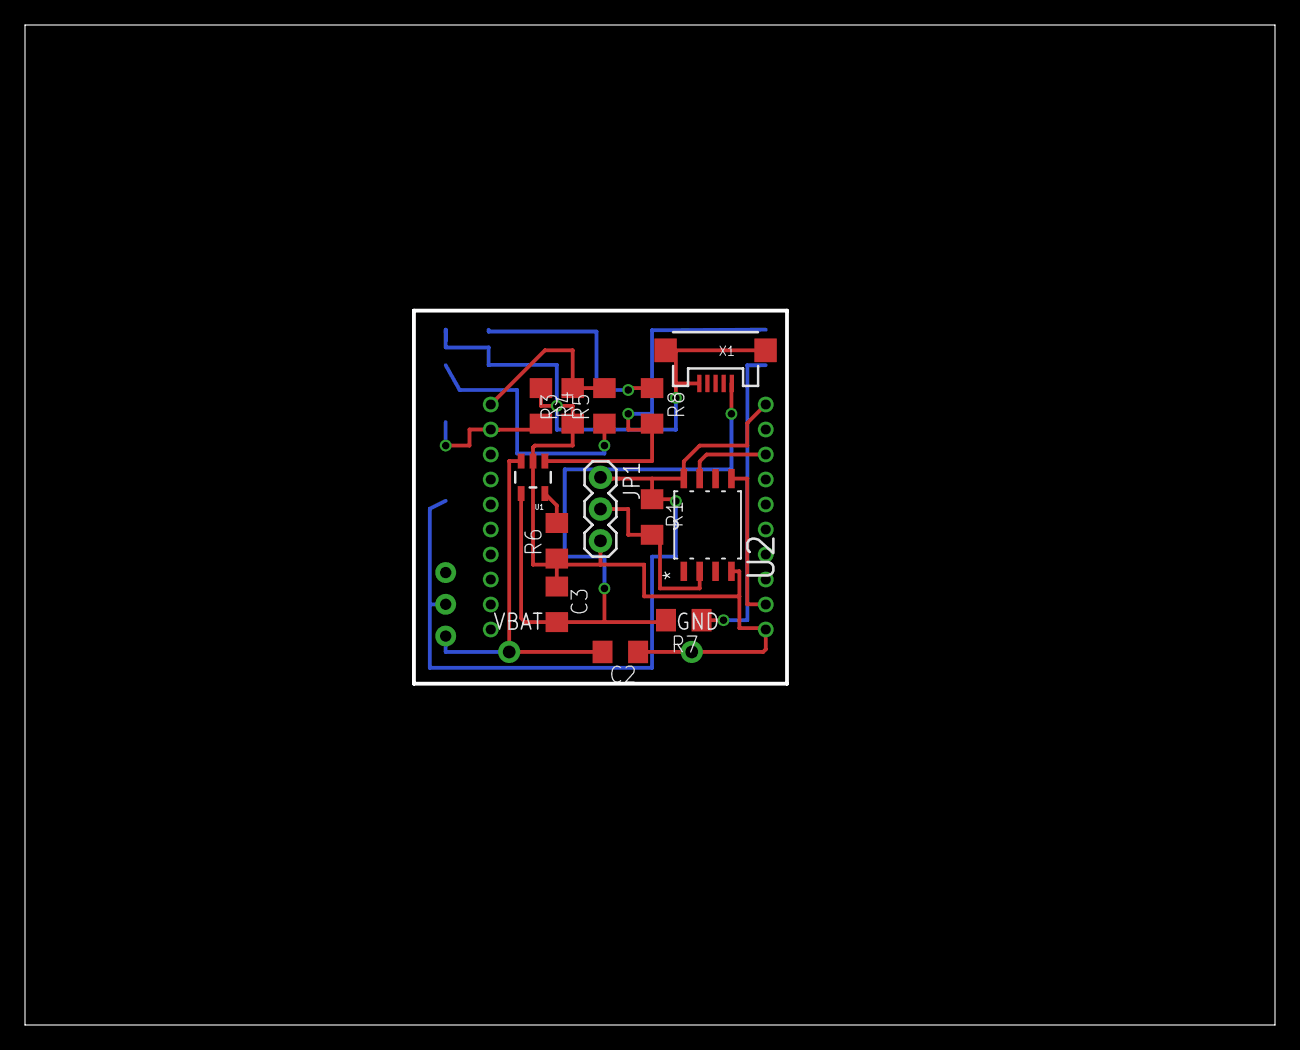
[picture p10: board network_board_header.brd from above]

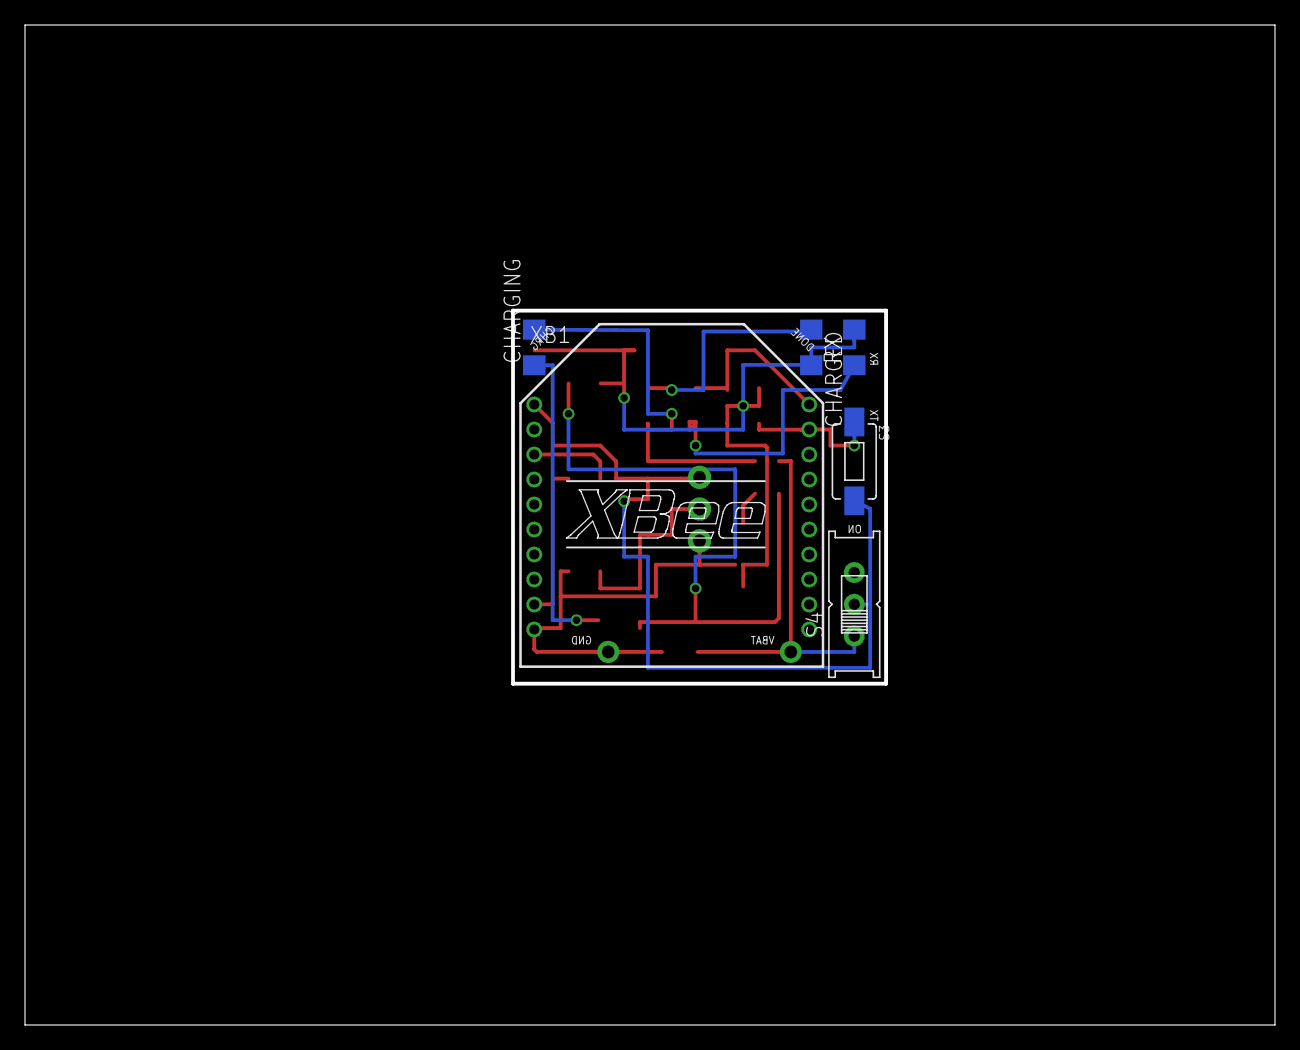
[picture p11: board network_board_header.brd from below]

Board: 2 copper layers, 100.0 x 80.0 mm, 21 parts (6 on the bottom side), 14 nets.

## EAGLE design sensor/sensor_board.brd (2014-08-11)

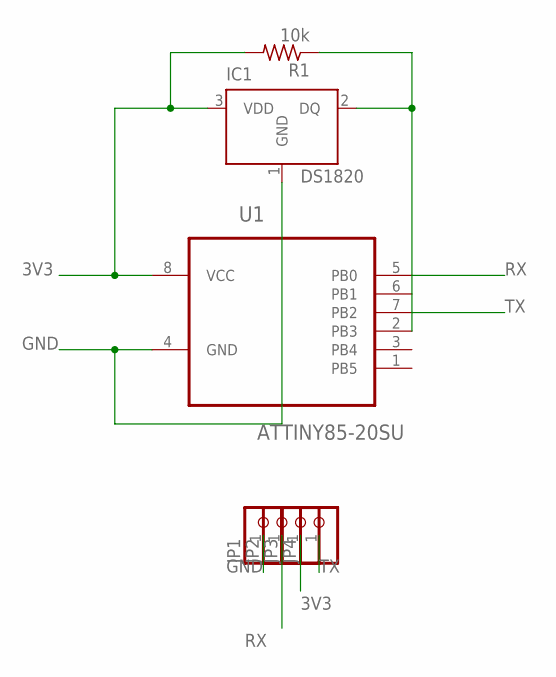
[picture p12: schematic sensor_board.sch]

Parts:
IC1: DS1820; TO-92
JP1, JP2, JP3, JP4: PINHD-1X1; 1X01
R1: 10k; R1206
U1: ATTINY85-20SU; SOIC127P798X216-8N

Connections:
3V3: IC1.3 (VDD), JP3.1, R1.2, U1.8 (VCC)
GND: IC1.1 (GND), JP1.1, U1.4 (GND)
unnamed: IC1.2 (DQ), R1.1, U1.2 (PB3)
RX: JP2.1, U1.5 (PB0)
TX: JP4.1, U1.7 (PB2)

Board: 2 copper layers, 7 parts (0 on the bottom side), 5 nets, no tracks yet.

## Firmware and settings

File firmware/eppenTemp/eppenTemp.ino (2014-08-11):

/* 
  Charles Fracchia  1 Aug 2014
  Version that uses 9bit resolution of temperature
  Modified from: http://www.netfluvia.org/code/ds18B20_test.pde
*/

#include <SoftwareSerial.h>
#include <OneWire.h>

SoftwareSerial tinySerial(8, 2); // RX, TX

#define BAUDRATE 9600
#define TEMPSENSOR 3  // arduino i/o port connected to the ds18B20
//#define DEBUG         // uncomment for verbose output

/* some defines to make more legible checks into data read from the device 
 *   (see the DS18B20 datasheet for more detail)
 */ 
#define TEMP_LSB 0
#define TEMP_MSB 1
#define TH_REG 2
#define USERBYTE_1 2
#define TL_REG 3
#define USERBYTE_2 3
#define CONFIG_REG 4
#define CRC 8

OneWire ds(TEMPSENSOR); 

void setup() {
  tinySerial.begin(BAUDRATE);
  byte addr[8];
  /* modify scratchpad register to set temp sampling resolution */
  ds.reset();
  ds.select(addr);    
  ds.write(0x4E);          // write scratchpad (starts at byte 2)
  // note:  set high/low temp alarms by changing the next two values 
  ds.write(0x4B);    // default value of TH reg (user byte 1)
  ds.write(0x46);    // default value of TL reg (user byte 2)
  // uncomment one of the following
  //ds.write(0x7F);    // 12-bit sampling resolution (default)
  //ds.write(0x5F);    // 11-bit
  //ds.write(0x3F);    // 10-bit
  ds.write(0x1F);    // 9-bit
  
}

/* convert celsius to fahrenheit
 *
 *   takes: float
 * returns: float
 */
float c2f(float cel) {
  return (cel * (9.0/5.0)) + (float)32;
}

/* read temp from DS18B20 sensor using one-wire protocol */
void loop() {

  byte i;
  byte present = 0;
  byte data[12];
  byte addr[8];

  int temp_c_int;
  float temp_c_frac;
  float temp_c;
  float temp_f;
  int test_bit;
  int set_bit;
  int resolution_floor;
  float expon;
  
  if ( !ds.search(addr)) {
      ds.reset_search();
      return;
  }

  /* print the address - might be useful for non-debug mode if you have
   *   >1 devices on the bus
   */
#ifdef DEBUG
  tinySerial.print("R=");
  for( i = 0; i < 8; i++) {
    tinySerial.print(addr[i], HEX);
    tinySerial.print(" ");
  }
#endif

  if ( OneWire::crc8( addr, 7) != addr[7]) {
      tinySerial.print("CRC is not valid!\n");
      return;
  }

  if ( addr[0] != 0x28) {
      tinySerial.print("Device is not a DS18B20 family device.\n");
      return;
  }

  ds.reset();
  ds.select(addr);
  ds.write(0x44, 1);    // start conversion, with parasite power on at the end

  delay(1000);     // maybe 750ms is enough, maybe not
  // we might do a ds.depower() here, but the reset will take care of it.

  present = ds.reset();
  ds.select(addr);    
  ds.write(0xBE);          // Read Scratchpad

  if (!present) {
    tinySerial.print("ERROR: selected device not present\n");
    return;
  }
  
  for ( i = 0; i < 9; i++) {           // we need 9 bytes
    data[i] = ds.read();
#ifdef DEBUG
    tinySerial.print(data[i], HEX);
    tinySerial.print(" ");
#endif
  }

  if (data[8] != OneWire::crc8(data,8)) {
    tinySerial.print("ERROR: CRC didn't match\n");
    return;
  }
  
  /* print raw bytes from which we'll extract temp data */
#ifdef DEBUG 
  tinySerial.print("[MSB:");
  tinySerial.print(data[TEMP_MSB],BIN);
  tinySerial.print(" LSB:");
  tinySerial.print(data[TEMP_LSB],BIN);
  tinySerial.print("] ");
#endif
  
  /* compute the degrees in celcius / integer part */
  temp_c_int = 0;
  
  /* The measured temp is spread across two bytes of the returned data.
   *  The integer part of the temp value is spread across the least 3 significant
   *  bits of the most significant byte (MSB) and the most significant 4 of 
   *  the LSB.  Here we shift those 7 bits into their proper place in our
   *  result byte. 
   *
   * note: could do this with 2 bit-shift / mask operations, alternatively
   */
  set_bit = 6;
  for (test_bit = 2; test_bit >= 0; test_bit--) {
    temp_c_int |= ( ((data[TEMP_MSB] & (1 << test_bit)) >> test_bit) << set_bit );
    set_bit--;
  }
  for (test_bit = 7; test_bit >= 4; test_bit--) {
    temp_c_int |= ( ((data[TEMP_LSB] & (1 << test_bit)) >> test_bit) << set_bit );
    set_bit--;
  }

#ifdef DEBUG
  tinySerial.print(temp_c_int,DEC);
#endif

  /* compute the fractional part */

  /*  first figure out what resolution we're measuring in - varies between 1 and 4 bits
   *    after the decimal (based on the contents of the CONFIG_REG byte):
   *        bit 6 == 0 && bit 5 == 0 --> 9-bit resolution (ignore 3 least sig bits)
   *        bit 6 == 0 && bit 5 == 1 --> 10-bit resolution (ignore 2 least sig bits)
   *        bit 6 == 1 && bit 5 == 0 --> 11-bit resolution (ignore 1 least sig bits)
   *        bit 6 == 1 && bit 5 == 1 --> 12-bit resolution   
   */
  if ((data[CONFIG_REG] & (1 << 5)) > 0) {        
    if ((data[CONFIG_REG] & (1 << 4)) > 0) {      // bits 6 and 5 are set
      resolution_floor = 0;
    } else {                                      // bit 6 is set, 5 is clear
      resolution_floor = 1;
    }
  } else {
    if ((data[CONFIG_REG] & (1 << 4)) > 0) {      // bits 6 is clear, 5 is set
      resolution_floor = 2;
    } else {                                      // bit 6 and 5 are clear
      resolution_floor = 3;
    }
  }    

  temp_c_frac = 0;
  for (test_bit = 3; test_bit >= resolution_floor; test_bit--) {
    if ((data[TEMP_LSB] & (1 << test_bit)) > 0) {
      expon = test_bit - 4; // will be negative
      temp_c_frac += pow(2,expon);
    }
  }
#ifdef DEBUG
  tinySerial.print(" ");
  tinySerial.print(temp_c_frac * 10000,DEC);
#endif

  /* put it all together */
  temp_c = (float)temp_c_int + temp_c_frac;  

  if ((data[TEMP_MSB] & (1 << 7)) > 0) {   // the temp is negative
    temp_c *= -1;
  }

  temp_f = c2f(temp_c);
  
  tinySerial.print("R=");
  tinySerial.print(temp_c,DEC); // tinySerial.print truncates after the decimal pt
  //tinySerial.print(" F=");
  //tinySerial.print(temp_f,DEC);
  
  tinySerial.print("\n");  
}

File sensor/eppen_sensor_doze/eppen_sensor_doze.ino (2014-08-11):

//eppen_sensor.ino
//by Andrew Payne 
//rev. 06/11/14
//cribs from http://tushev.org/articles/arduino/item/52-how-it-works-ds18b20-and-arduino

#include <SoftwareSerial.h>
#include <OneWire.h>

OneWire ds(3);
SoftwareSerial tinySerial(8, 2); // RX, TX


#define DS18S20_ID 0x10
#define DS18B20_ID 0x28


void setup()  
{
  tinySerial.begin(9600);
  pinMode(0,OUTPUT);
}

void loop(void)
{
  byte i;
  byte data[12];
  byte addr[8];
  float temp;

  //each sensor has a unique ID
  if (!ds.search(addr)) {
      ds.reset_search();
      return;
  }
  
  //check for valid ID
  if (OneWire::crc8(addr,7) != addr[7]){
    return;
  }  
  if (addr[0] != DS18B20_ID){
    return;
  }
  
  ds.reset(); //needed before any communication can occur
  ds.select(addr);
  
  //0x44 is CONVERT command for data conversion for 2-byte measurement 
  ds.write(0x44, 1); //measurement is stored in sensor scratchpad (RAM)
  delay(9995); 
  ds.reset();
  ds.select(addr);
  
  //0xBE is READ SCRATCHPAD -> 9 data bytes expected
  ds.write(0xBE);
  for (i = 0; i < 9; i++) {
    data[i] = ds.read();
  }
  //multiply by sensor resolution
  temp = ( (data[1] << 8) + data[0])*0.0625;
  
  digitalWrite(0, LOW);
  delay(4);
  tinySerial.print("ID=1112 R=");
  tinySerial.print(temp);
  tinySerial.print("\n");
  delay(1);
  digitalWrite(0, HIGH);
}

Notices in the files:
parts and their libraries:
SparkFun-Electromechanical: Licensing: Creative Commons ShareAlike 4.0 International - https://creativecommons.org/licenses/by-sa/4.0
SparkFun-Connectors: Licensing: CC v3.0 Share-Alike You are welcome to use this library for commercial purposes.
